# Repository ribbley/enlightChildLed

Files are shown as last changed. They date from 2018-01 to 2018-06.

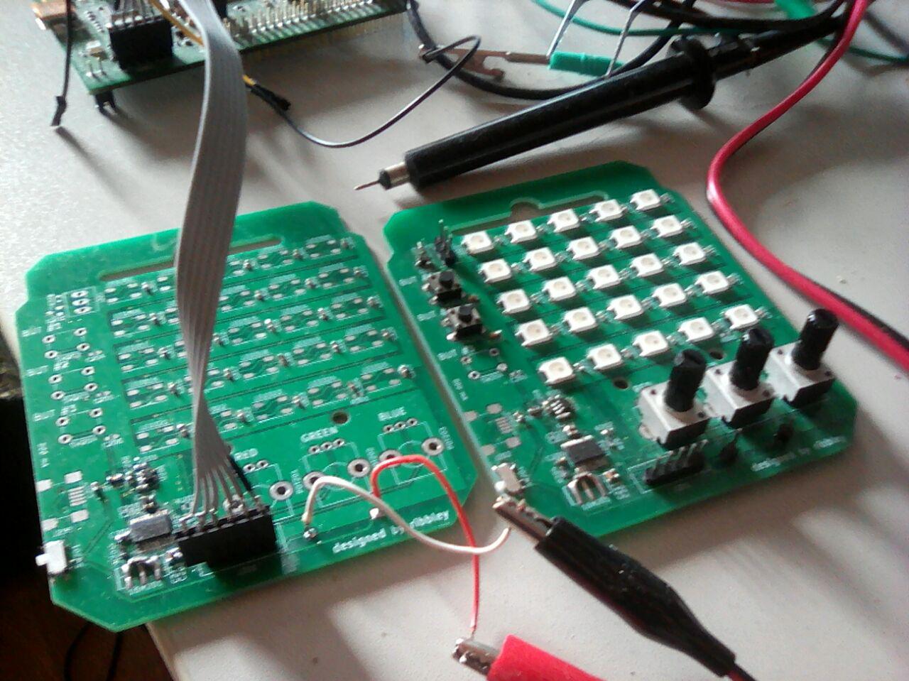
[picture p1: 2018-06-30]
pcb/documentation/enlight_pcbs.jpg

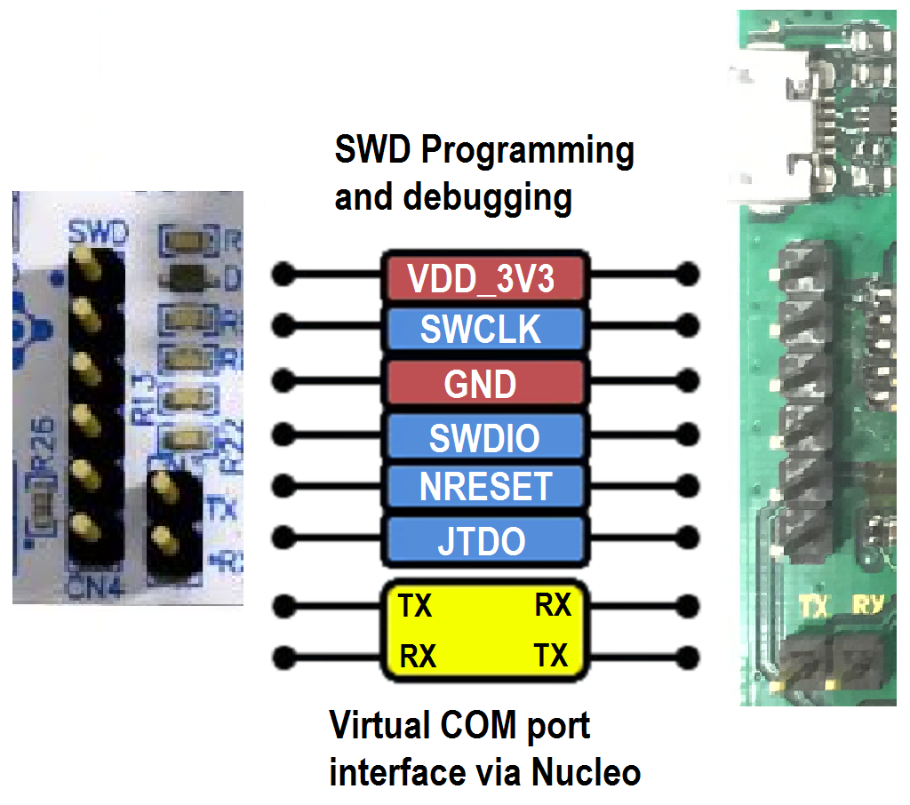
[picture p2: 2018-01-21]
pcb/datasheets/swd_header.png

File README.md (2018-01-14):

# enlightChildLed
Small gadget for kids to play with and learn additive color mixing.

# TODOs:
- add pcb design files (KiCAD)
- document process (design, component search, ordering, assembly, firmware-developing, testing)
- add real photos

# Contact me, if you want to learn more about this project!

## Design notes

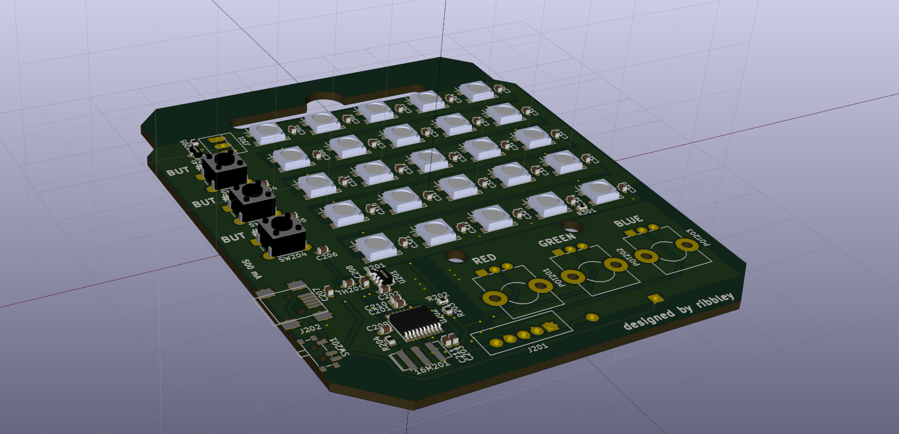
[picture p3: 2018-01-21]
pcb/documentation/enlightChildLed.png

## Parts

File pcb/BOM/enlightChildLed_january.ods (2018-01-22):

Title | Enlight Child LED (worktitle)
Revision | 0.0.1
Date
Generated | Do 21 Dez 2017 11:23:52 CET
Company
Comment 1
Comment 2
Comment 3
Comment 4
Total Parts | 83
Total Unique Parts | 23
Ref | Qty | Value | Footprint | Digikey | Count | Price | Anm.: | Aliexpress | Count | Price | Anm.:
BT201 | 1 | Battery | Battery_Holders:Keystone_2479_3xAAA | BA3AAPC-ND | 10 | 27,42 |  |  | 10 | 8,1 | $ | https://www.aliexpress.com/item/1pcs-Set-18650-Li-ion-Battery-For-Flashlight-For-4-6800mah-18650-Li-ion-Battery-1/32790079648.html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
C202 C209 C201 C325 C324 C323 C322 C321 C320 C319 C318 C317 C316 C315 C314 C313 C312 C311 C310 C309 C308 C307 C306 C305 C304 C303 C302 C301 | 28 | 100n | Capacitors_SMD:C_0603 | 399-1095-2-ND | 4000 | 17,78 |  |  | 500 | 4,99 | $ | https://www.aliexpress.com/item/100pcs-lot-18pF-NPO-Error-5-50V-0603-smd-capacitor/32319259131.html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
C203 | 1 | 1u | Capacitors_SMD:C_0603 | 399-3118-1-ND | 10 | 0,41 |  |  | 200 | 1,3 | $ | https://www.aliexpress.com/item/Free-shipping-0603-SMD-capacitor-1UF-50V-105M-100PCS/32371840299.html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
C210 | 1 | 4.7u | Capacitors_SMD:C_0603 | 1276-6684-1-ND | 10 | 0,88 |  |  | 200 | 2,58 | $ | https://www.aliexpress.com/item/MCIGICM-200pcs-0805-smd-capacitor-ceramic-22pf-100nf-1uf-2-2uf-4-7uf-10uf-47uf-22uf/32842027469.html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
C205 C206 C204 C211 | 4 | 10n | Capacitors_SMD:C_0603 | 732-7933-1-ND | 50 | 1,62 |  |  | 200 | 1,5 | $ | https://www.aliexpress.com/item/MCIGICM-200pcs-0805-smd-capacitor-ceramic-22pf-100nf-1uf-2-2uf-4-7uf-10uf-47uf-22uf/32842027469.html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
C208 C207 | 2 | 10u | Capacitors_SMD:C_0603 | 587-3258-1-ND | 20 | 2,22 |  |  | 200 | 3 | $ | https://www.aliexpress.com/item/MCIGICM-200pcs-0805-smd-capacitor-ceramic-22pf-100nf-1uf-2-2uf-4-7uf-10uf-47uf-22uf/32842027469.html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
J201 | 1 | CONN_01X05 | Connectors:Wafer_Vertical15x5.8x7RM2.5-5 | - |  |  |  | same as I24 |  |  | see below
J202 | 1 | USB_OTG | Connectors:USB_Mini-B | 609-4613-1-ND | 10 | 3,66 |  |  | 10 | 0,87 | $ | https://www.aliexpress.com/item/Free-Shipping-10pcs-Micro-USB-5pin-B-type-Female-Connector-For-Mobile-Phone-Micro-USB/32696736555.html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
J301 | 1 | CONN_01X03_FEMALE | Connectors:PINHEAD1-3 | - |  |  |  |  | 10x40 | 1,07 | $ | https://www.aliexpress.com/item/PinHeader-Male-10lines-40pin-BLACK-2-54mm-Pitch-Straight-PL-11-5-Single-Row/32806123987.html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
LED325 LED324 LED323 LED322 LED321 LED320 LED319 LED318 LED317 LED316 LED315 LED314 LED313 LED312 LED311 LED310 LED309 LED308 LED307 LED306 LED305 LED304 LED303 LED302 LED301 | 25 | WS2812B | LEDs:LED_WS2812B-PLCC4 | NA |  |  |  |  | 200 | 12,15 | 250 needed
16M201 | 1 | Crystal_GND3 | Crystals:Resonator_SMD_muRata_SFSKA-3pin_7.9x3.8mm | 1253-1084-1-ND | 10 | 5,3 |  | not available
POT201 POT202 POT203 | 3 | >500k | Potentiometers:Potentiometer_Bourns_PTV09A-1_Horizontal | PTV09A-4020F-A504-ND | 30 | 16,87 |  | not available
Q201 | 1 | Q_NPN_BCE | TO_SOT_Packages_SMD:SOT-23 | ZXTN07012EFFCT-ND | 10 | 5,12 |  |  | 100 | 1,1 | $ | https://www.aliexpress.com/item/Free-Shipping-100PCS-SMD-S8050-J3Y-NPN-SMD-Transistor-SOT-23/793888983.html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
R204 R201 | 2 | 10k | Resistors_SMD:R_0603 | 311-10KGRCT-ND | 20 | 0,18 |  | set A | 20 | 1,42 | $ | https://www.aliexpress.com/item/Free-shipping-Hot-sale-0603-SMD-Resistor-Kit-Assorted-Kit-1ohm-10M-ohm-1-36valuesX20pcs-720pcs/32359683117.html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
R202 | 1 | 1M | Resistors_SMD:R_0603 | 311-1.0MGRCT-ND | 10 | 0,09 |  | set A | 20
R203 | 1 | 1.5M | Resistors_SMD:R_0603 | 311-1.5MGRCT-ND | 10 | 0,09 |  | set A | 20
R205 | 1 | 5.6k | Resistors_SMD:R_0603 | 541-5.10KHCT-ND | 10 | 0,35 | 5.1k !! | set A | 20
R301 | 1 | 4.7M | Resistors_SMD:R_0603 | 311-5.1MGRCT-ND | 10 | 0,09 |  | set A | 20
SW201 | 1 | SW_DPDT_x2 | Buttons_Switches_SMD:SW_SPDT_PCM12 | ?? |  |  |  | Only 0.3 A | 50 | 5,57 | $ | https://www.aliexpress.com/item/On-Off-2-Position-SPDT-Horizontal-Miniature-SMT-SMD-Slide-Switch/32224673665.html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
SW202 SW203 SW204 | 3 | SW_Push | Buttons_Switches_THT:SW_PUSH_6mm | 450-1650-ND | 30 | 2,2 |  |  | 100 | 1,13 | $ | https://www.aliexpress.com/item/100pcs-6-6-5mm-4pin-Quality-Mini-Micro-Momentary-Tactile-Push-Button-Switch/32753141267.html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
TH201 | 1 | above 500mA | Resistors_SMD:R_0402 | !!! |  |  |  |  | 20 | 1,12 | $ | https://www.aliexpress.com/item/20PCS-0805-500MA-0-5A-SMD-PTC-resettable-fuse/32705112154.html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
U202 | 1 | STM32F031F4Px | Housings_SSOP:TSSOP-20_4.4x6.5mm_Pitch0.65mm | 497-17338-ND | 10 | 12,66 | 16kB vers. | not available
U201 | 1 | AP131-33 | TO_SOT_Packages_SMD:SOT-23-5 | 576-4764-1-ND | 10 | 1 |  | not available
 |  |  |  | total: |  | 97,94 |  | total: |  | 37,638 | Eu
 |  |  |  | Price / Unit : |  | 9,794 |  |  |  | 3,7638
BOM made with KICAD_BOM_WIZARD (https://github.com/HashDefineElectronics/KiCad_BOM_Wizard.git) |  |  |  |  |  |  | Ordered | Type | Count | Price | Anm.: | Link
Generated Do 21 Dez 2017 11:23:52 CET |  |  |  |  |  |  | SMD CAP | 100 nF 0603 | 500 | 4,14 |  | https://www.aliexpress.com/item/100pcs-lot-18pF-NPO-Error-5-50V-0603-smd-capacitor/32319259131.html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
 |  |  |  |  |  |  | SMD CAP | 1 µF 0603 | 200 | 1,08 |  | https://www.aliexpress.com/item/Free-shipping-0603-SMD-capacitor-1UF-50V-105M-100PCS/32371840299.html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
 |  |  |  |  |  |  | BATT HOLDER | 3x AAA | 4 | 2,56 |  | https://www.aliexpress.com/item/1pcs-Set-18650-Li-ion-Battery-For-Flashlight-For-4-6800mah-18650-Li-ion-Battery-1/32790079648.html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
 |  |  |  |  |  |  | SMD CAP KIT | 4.7 µF 0603 | 20 | 2,82 |  | https://www.aliexpress.com/item/0603-SMD-Capacitor-assorted-kit-36values-20pcs-720pcs-1pF-10uF-Samples-Kit-electronic-diy-kit/32817046315.html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
 |  |  |  |  |  |  |  | 10 nF 0603 | 20
 |  |  |  |  |  |  |  | 10 µF 0603 | 20
 |  |  |  |  |  |  | CONN PINS | 5x 40 pin | 200 | 0,69 |  | https://www.aliexpress.com/item/Promotion-5-PCS-Pack-40-Pin-2-54mm-Single-Row-Straight-Male-Female-Pin-Header-Strip/32598438788.html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
 |  |  |  |  |  |  | CONN USB | Micro female | 3 | 2,16 |  | https://www.aliexpress.com/item/Free-Shipping-10pcs-Micro-USB-5pin-B-type-Female-Connector-For-Mobile-Phone-Micro-USB/32696736555.html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
 |  |  |  |  |  |  | NPN TRANS | SOT-23 | 100 | 0,83 |  | https://www.aliexpress.com/item/Free-Shipping-100PCS-SMD-S8050-J3Y-NPN-SMD-Transistor-SOT-23/793888983.html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
 |  |  |  |  |  |  | SMD RES KIT | 10k 0603 | 20 | 1,2 |  | https://www.aliexpress.com/item/Free-shipping-Hot-sale-0603-SMD-Resistor-Kit-Assorted-Kit-1ohm-10M-ohm-1-36valuesX20pcs-720pcs/32359683117.html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
 |  |  |  |  |  |  |  | 1M 0603 | 20
 |  |  |  |  |  |  |  | 1.5M 0603 | 20
 |  |  |  |  |  |  |  | 5.6k 0603 | 20
 |  |  |  |  |  |  |  | 4.7M 0603 | 20
 |  |  |  |  |  |  | SMD PTC | 500 mA 0805 | 20 | 0,93 |  | https://www.aliexpress.com/item/20PCS-0805-500MA-0-5A-SMD-PTC-resettable-fuse/32705112154.html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
 |  |  |  |  |  |  | SMD SWITCH | SPDT slide | 50 | 1,25 |  | https://www.aliexpress.com/item/MINI-micro-Slide-Switch-On-OFF-2-Position-1P2T-SPDT-Miniature-Horizontal-Slide-Switch-SMD-7/32841341185.html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
 |  |  |  |  |  |  | PUSH BUTTON | THT tactile | 100 | 0,94 |  | https://www.aliexpress.com/item/100pcs-6-6-5mm-4pin-Quality-Mini-Micro-Momentary-Tactile-Push-Button-Switch/32753141267.html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
 |  |  |  |  |  |  | SMD MCU | stm32f030f4p6 | 10 | 5,92 |  | https://www.aliexpress.com/item/Free-Shipping-10PCS-STM32F030F4P6-STM32F030/32533209137.html?priceBeautifyAB=1
 |  |  |  |  |  |  | LDO | 3.3V SOT-23-5 | 5 | 0,9 |  | https://www.aliexpress.com/item/Original-XC6228D332VR-G-SOT-23-5-3-3V-Low-Dropout-Linear-Regulator-5pcs-lot/32829424231.html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
 |  |  |  |  |  |  | SMART LED | WS2812B | 100 | 6,92 |  | https://de.aliexpress.com/item/10-1000pcs-WS2812B-4pins-5050-SMD-Black-White-version-WS2812-Individually-Addressable-Digital-RGB-LED-Chip/32453497583.html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
 |  |  |  |  |  |  | POT | 50k RV09 | 10 | 2,34 |  | https://de.aliexpress.com/item/5PCS-LOT-B50K-B503-RV09-Potentiometer-Adjustable-Resistance-12-5mm-Shaft-3-Pins-0932-Vertical-adjustable/32803687010.html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
 |  |  |  |  |  |  | OSC | 8MHz 0805 | 10 | 3,12 |  | https://de.aliexpress.com/store/product/Free-shiiping-10pcs-8MHz-10pF-3Pin-3213-smd-quartz-resonator-Crystal-oscillator/506373_32326095241.html
 |  |  |  |  |  |  |  |  | Sum: | 37,8
 |  |  |  |  |  |  |  |  | Shipping add: | 0,44
 |  |  |  |  |  |  |  |  | TOTAL: | 38,24

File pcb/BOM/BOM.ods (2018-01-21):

 |  | Requirements | URL
Ceramic Crystal Oscillator |  | 16 Mhz | https://de.rs-online.com/web/p/keramik-resonatoren/7027263/
Potentiometer |  | >500kOhm | https://de.rs-online.com/web/p/potenziometer/7377811/
Switch |  | 3 PIN >=500mA | https://www.digikey.de/product-detail/de/e-switch/EG1224/EG2585-ND/502052
Button |  | SMD | https://www.digikey.de/product-detail/de/te-connectivity-alcoswitch-switches/1825910-6/450-1650-ND/1632536
NPN |  | <100ns response | beliebiger SOT-23
Thermistor | PTC | 500 mA Tripping Current | https://www.digikey.de/product-detail/de/bel-fuse-inc/0ZCJ0025AF2E/507-1799-2-ND/4156274
Batteryholder |  |  | http://www.memoryprotectiondevices.com/datasheets/BA3AAPC-datasheet.pdf

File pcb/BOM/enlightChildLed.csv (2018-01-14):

Title | Enlight Child LED (worktitle)
Revision | 0.0.1
Date
Generated | Do 21 Dez 2017 11:23:52 CET
Company
Comment 1
Comment 2
Comment 3
Comment 4
Total Parts | 83
Total Unique Parts | 23
Ref | Qty | Value | Footprint | Digikey | Count | Price | Anm.: | Aliexpress | Count | Price | Anm.:
BT201 | 1 | Battery | Battery_Holders:Keystone_2479_3xAAA | BA3AAPC-ND | 10 | 27.42
C202 C209 C201 C325 C324 C323 C322 C321 C320 C319 C318 C317 C316 C315 C314 C313 C312 C311 C310 C309 C308 C307 C306 C305 C304 C303 C302 C301 | 28 | 100n | Capacitors_SMD:C_0603 | 399-1095-2-ND | 4000 | 17.78
C203 | 1 | 1u | Capacitors_SMD:C_0603 | 399-3118-1-ND | 10 | 0.41
C210 | 1 | 4.7u | Capacitors_SMD:C_0603 | 1276-6684-1-ND | 10 | 0.88
C205 C206 C204 C211 | 4 | 10n | Capacitors_SMD:C_0603 | 732-7933-1-ND | 50 | 1.62
C208 C207 | 2 | 10u | Capacitors_SMD:C_0603 | 587-3258-1-ND | 20 | 2.22
J201 | 1 | CONN_01X05 | Connectors:Wafer_Vertical15x5.8x7RM2.5-5 | -
J202 | 1 | USB_OTG | Connectors:USB_Mini-B | 609-4613-1-ND | 10 | 3.66
J301 | 1 | CONN_01X03_FEMALE | Connectors:PINHEAD1-3 | -
LED325 LED324 LED323 LED322 LED321 LED320 LED319 LED318 LED317 LED316 LED315 LED314 LED313 LED312 LED311 LED310 LED309 LED308 LED307 LED306 LED305 LED304 LED303 LED302 LED301 | 25 | WS2812B | LEDs:LED_WS2812B-PLCC4 | NA |  |  |  |  | 200 | 12.15 | 250 needed
16M201 | 1 | Crystal_GND3 | Crystals:Resonator_SMD_muRata_SFSKA-3pin_7.9x3.8mm | 1253-1084-1-ND | 10 | 5.3
POT201 POT202 POT203 | 3 | >500k | Potentiometers:Potentiometer_Bourns_PTV09A-1_Horizontal | PTV09A-4020F-A504-ND | 30 | 16.87
Q201 | 1 | Q_NPN_BCE | TO_SOT_Packages_SMD:SOT-23 | ZXTN07012EFFCT-ND | 10 | 5.12
R204 R201 | 2 | 10k | Resistors_SMD:R_0603 | 311-10KGRCT-ND | 20 | 0.18
R202 | 1 | 1M | Resistors_SMD:R_0603 | 311-1.0MGRCT-ND | 10 | 0.09
R203 | 1 | 1.5M | Resistors_SMD:R_0603 | 311-1.5MGRCT-ND | 10 | 0.09
R205 | 1 | 5.6k | Resistors_SMD:R_0603 | 541-5.10KHCT-ND | 10 | 0.35 | 5.1k !!
R301 | 1 | 4.7M | Resistors_SMD:R_0603 | 311-5.1MGRCT-ND | 10 | 0.09
SW201 | 1 | SW_DPDT_x2 | Buttons_Switches_SMD:SW_SPDT_PCM12 | ??
SW202 SW203 SW204 | 3 | SW_Push | Buttons_Switches_THT:SW_PUSH_6mm | 450-1650-ND | 30 | 2.2
TH201 | 1 | above 500mA | Resistors_SMD:R_0402 | !!!
U202 | 1 | STM32F031F4Px | Housings_SSOP:TSSOP-20_4.4x6.5mm_Pitch0.65mm | 497-17338-ND | 10 | 12.66 | 16kB vers.
U201 | 1 | AP131-33 | TO_SOT_Packages_SMD:SOT-23-5 | 576-4764-1-ND | 10 | 1
 |  |  |  | total: |  | 97.94 |  | total: |  | 12.15
BOM made with KICAD_BOM_WIZARD (https://github.com/HashDefineElectronics/KiCad_BOM_Wizard.git)
Generated Do 21 Dez 2017 11:23:52 CET

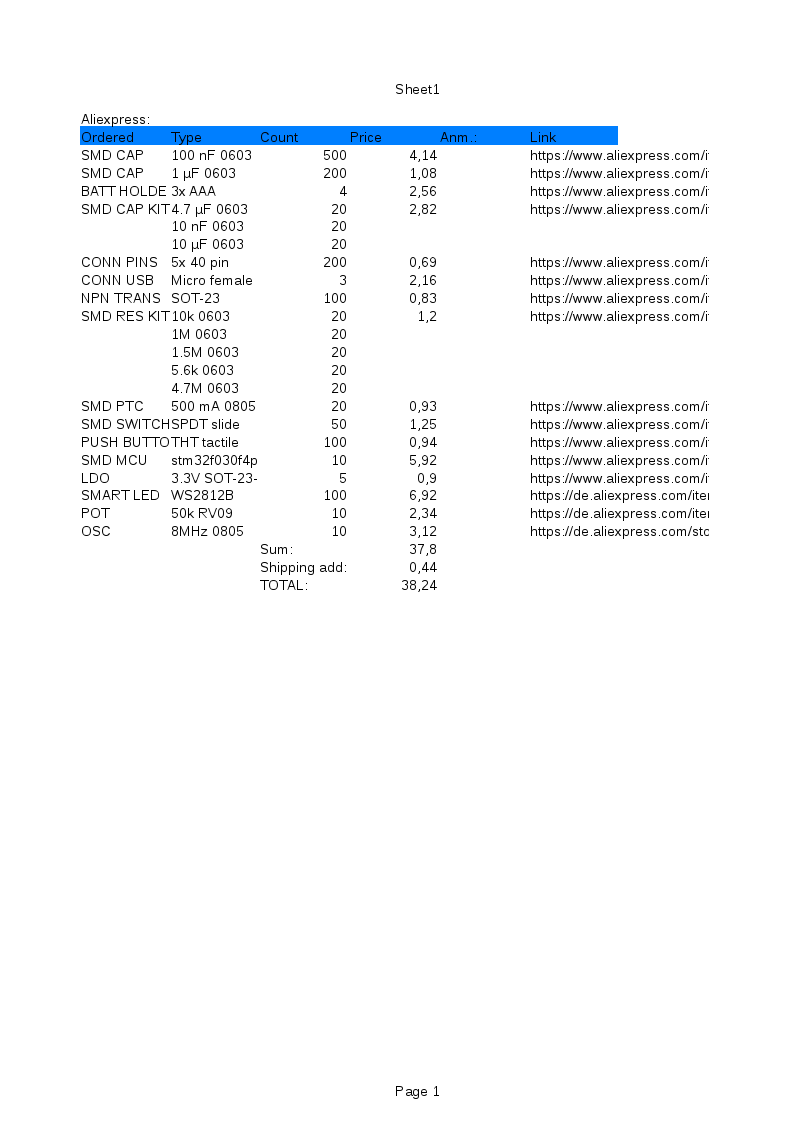
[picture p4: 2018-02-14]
pcb/BOM/order_22_01_2018.png

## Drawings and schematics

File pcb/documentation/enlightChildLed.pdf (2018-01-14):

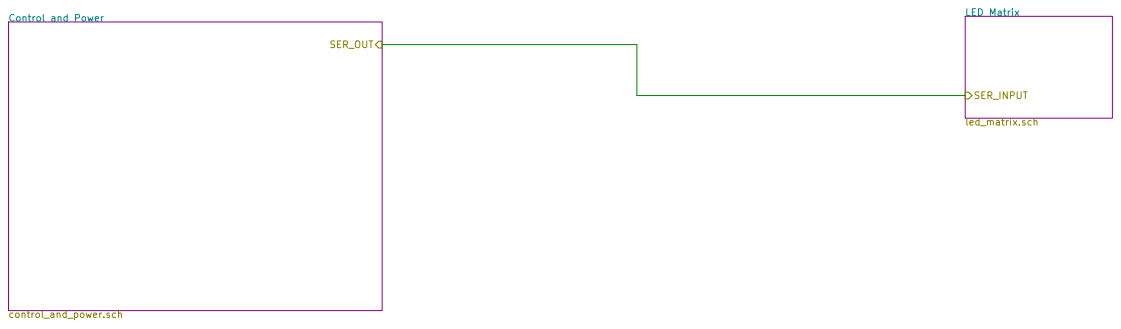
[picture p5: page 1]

File: enlightChildLed.sch Sheet: /
Id: 1/3 Title: Enlight Child LED (worktitle)

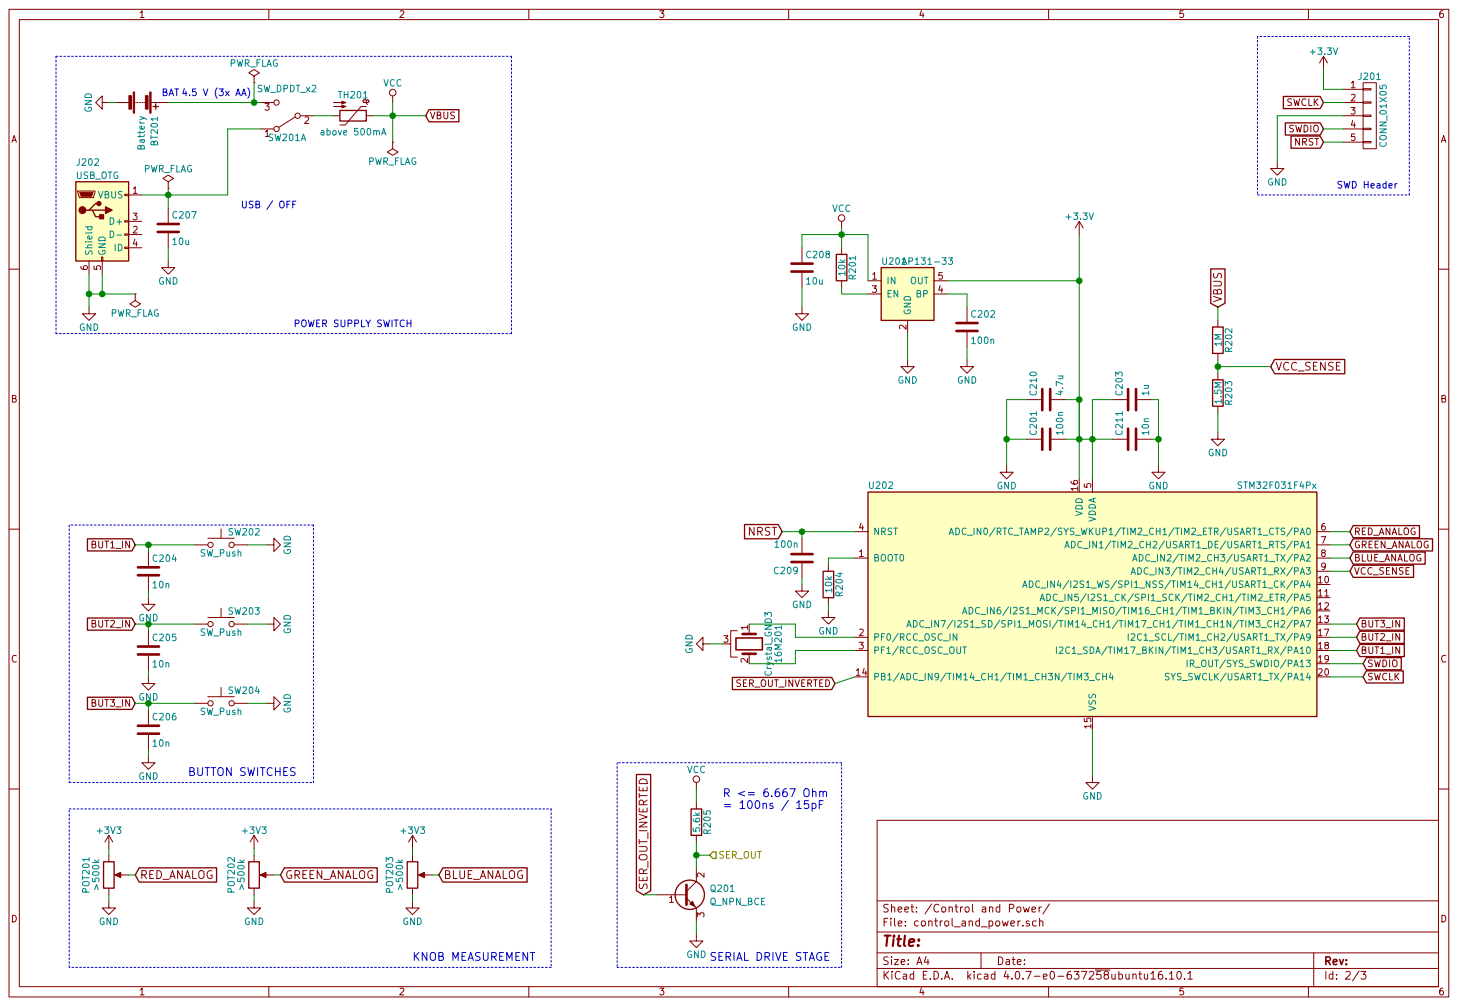
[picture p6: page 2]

2 EN 3 BP 4 OUT 5 U201 AP131-33 GND

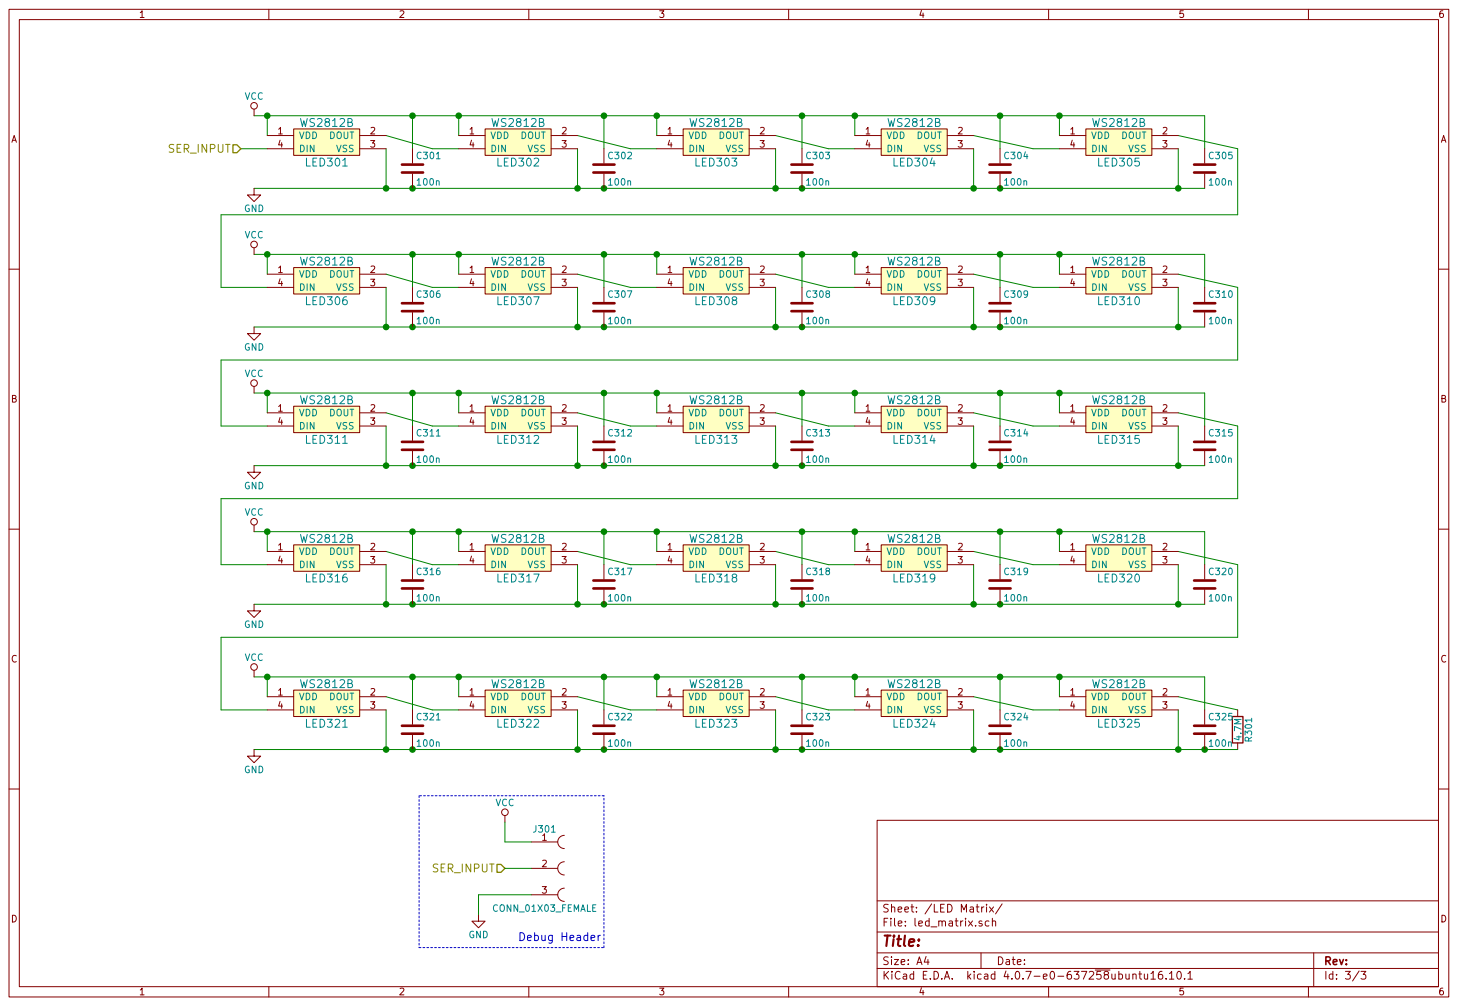
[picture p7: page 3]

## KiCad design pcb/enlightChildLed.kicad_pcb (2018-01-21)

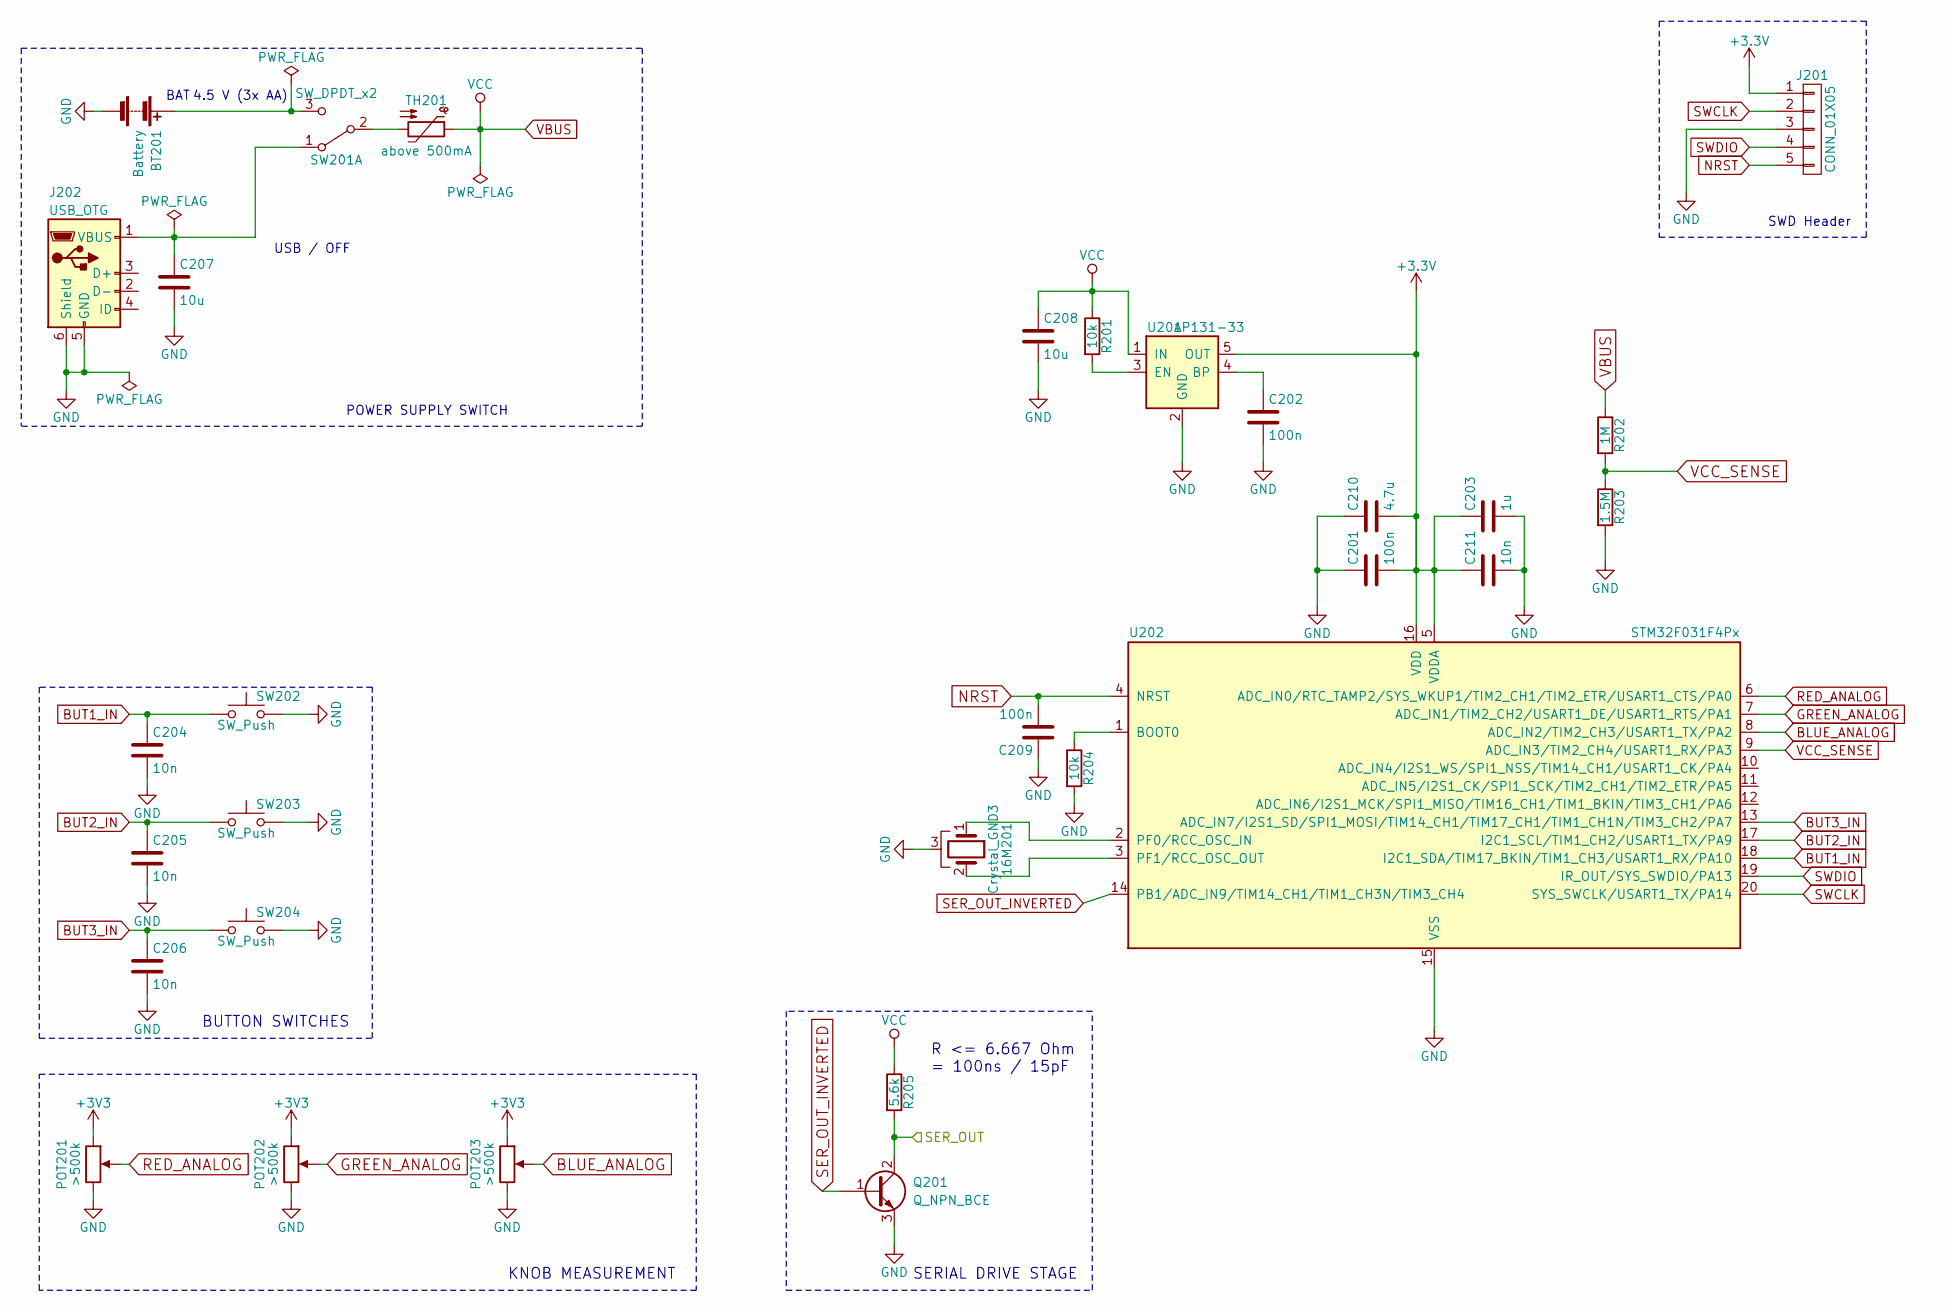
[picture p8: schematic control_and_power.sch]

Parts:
16M201: Crystal_GND3; Resonator_SMD_muRata_SFSKA-3pin_7.9x3.8mm
BT201: Battery; Keystone_2479_3xAAA
C201, C202, C209: 100n; C_0603
C203: 1u; C_0603
C204, C205, C206, C211: 10n; C_0603
C207, C208: 10u; C_0603
C210: 4.7u; C_0603
J201: CONN_01X05; Wafer_Vertical15x5.8x7RM2.5-5
J202: USB_OTG; USB_Mini-B
POT201, POT202, POT203: >500k; Potentiometer_Bourns_PTV09A-1_Horizontal
Q201: Q_NPN_BCE; SOT-23
R201, R204: 10k; R_0603
R202: 1M; R_0603
R203: 1.5M; R_0603
R205: 5.6k; R_0603
SW201: SW_DPDT_x2; SW_SPDT_PCM12
SW202, SW203, SW204: SW_Push; SW_PUSH_6mm
TH201: above 500mA; R_0402
U201: AP131-33; SOT-23-5
U202: STM32F031F4Px; TSSOP-20_4.4x6.5mm_Pitch0.65mm

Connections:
/LED Matrix/SER_INPUT: Q201.2 (C), R205.2; also elsewhere on the board
BLUE_ANALOG: POT203.2, U202.8 (ADC_IN2/TIM2_CH3/USART1_TX/PA2)
BUT1_IN: C204.1, SW202.1, U202.18 (I2C1_SDA/TIM17_BKIN/TIM1_CH3/USART1_RX/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)
BUT2_IN: C205.1, SW203.1, U202.17 (I2C1_SCL/TIM1_CH2/USART1_TX/PA9)
BUT3_IN: C206.1, SW204.1, U202.13 (ADC_IN7/I2S1_SD/SPI1_MOSI/TIM14_CH1/TIM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)
GND: 16M201.3, BT201.2 (-), C201.1, C202.2, C203.2, C204.2, C205.2, C206.2, C207.2, C208.2, C209.1, C210.1, C211.2, J201.3, J202.5 (GND), J202.6 (Shield), POT201.3, POT202.3, POT203.3, Q201.3 (E), R203.2, R204.2, SW202.2, SW203.2, SW204.2, U201.2 (GND), U202.15 (VSS); also elsewhere on the board
GREEN_ANALOG: POT202.2, U202.7 (ADC_IN1/TIM2_CH2/USART1_DE/USART1_RTS/P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)
NRST: C209.2, J201.5, U202.4 (NRST)
unnamed: 16M201.1, U202.2 (PF0/RCC_OSC_IN)
unnamed: 16M201.2, U202.3 (PF1/RCC_OSC_OUT)
unnamed: BT201.1 (+), SW201.3 (C)
unnamed: C202.1, U201.4 (BP)
unnamed: C207.1, J202.1 (VBUS), SW201.1 (A)
unnamed: R201.2, U201.3 (EN)
unnamed: R204.1, U202.1 (BOOT0)
unnamed: SW201.2 (B), TH201.2
RED_ANALOG: POT201.2, U202.6 (ADC_IN0/RTC_TAMP2/SYS_WKUP1/TIM2_CH1/TI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)
SER_OUT_INVERTED: Q201.1 (B), U202.14 (PB1/ADC_IN9/TIM14_CH1/TIM1_CH3N/TIM3_CH4)
SWCLK: J201.2, U202.20 (SYS_SWCLK/USART1_TX/PA14)
SWDIO: J201.4, U202.19 (IR_OUT/SYS_SWDIO/PA13)
VBUS: C208.1, R201.1, R202.1, R205.1, TH201.1, U201.1 (IN); also elsewhere on the board
VCC_SENSE: R202.2, R203.1, U202.9 (ADC_IN3/TIM2_CH4/USART1_RX/PA3)

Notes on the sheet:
SWD Header
USB / OFF
BAT
POWER SUPPLY SWITCH
4.5 V (3x AA)
KNOB MEASUREMENT
R <= 6.667 Ohm = 100ns / 15pF
SERIAL DRIVE STAGE
BUTTON SWITCHES

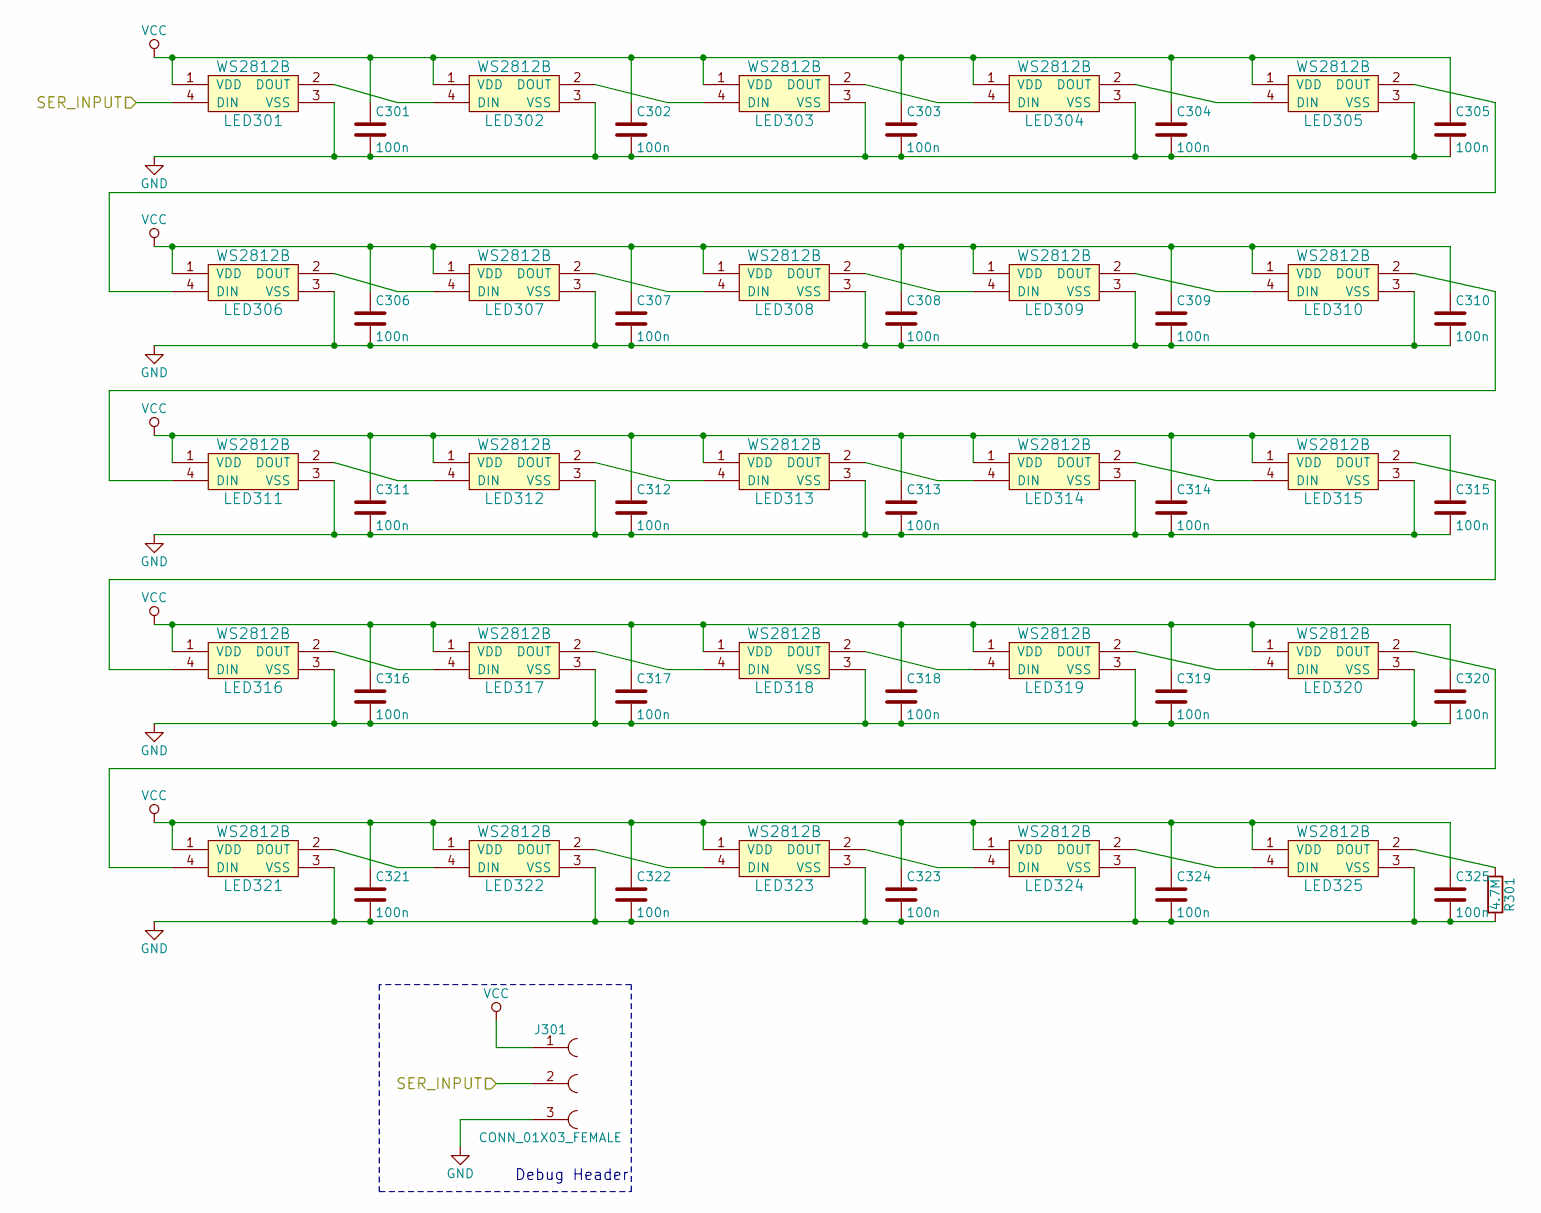
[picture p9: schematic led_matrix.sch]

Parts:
C301, C302, C303, C304, C305, C306, C307, C308, C309, C310, C311, C312, C313, C314, C315, C316, C317, C318, C319, C320, C321, C322, C323, C324, C325: 100n; C_0603
J301: CONN_01X03_FEMALE; PINHEAD1-3
LED301, LED302, LED303, LED304, LED305, LED306, LED307, LED308, LED309, LED310, LED311, LED312, LED313, LED314, LED315, LED316, LED317, LED318, LED319, LED320, LED321, LED322, LED323, LED324, LED325: WS2812B; LED_WS2812B-PLCC4
R301: 4.7M; R_0603

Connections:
/LED Matrix/SER_INPUT: J301.2, LED301.4 (DIN); also elsewhere on the board
GND: C301.2, C302.2, C303.2, C304.2, C305.2, C306.2, C307.2, C308.2, C309.2, C310.2, C311.2, C312.2, C313.2, C314.2, C315.2, C316.2, C317.2, C318.2, C319.2, C320.2, C321.2, C322.2, C323.2, C324.2, C325.2, J301.3, LED301.3 (VSS), LED302.3 (VSS), LED303.3 (VSS), LED304.3 (VSS), LED305.3 (VSS), LED306.3 (VSS), LED307.3 (VSS), LED308.3 (VSS), LED309.3 (VSS), LED310.3 (VSS), LED311.3 (VSS), LED312.3 (VSS), LED313.3 (VSS), LED314.3 (VSS), LED315.3 (VSS), LED316.3 (VSS), LED317.3 (VSS), LED318.3 (VSS), LED319.3 (VSS), LED320.3 (VSS), LED321.3 (VSS), LED322.3 (VSS), LED323.3 (VSS), LED324.3 (VSS), LED325.3 (VSS), R301.2; also elsewhere on the board
unnamed: LED301.2 (DOUT), LED302.4 (DIN)
unnamed: LED302.2 (DOUT), LED303.4 (DIN)
unnamed: LED303.2 (DOUT), LED304.4 (DIN)
unnamed: LED304.2 (DOUT), LED305.4 (DIN)
unnamed: LED305.2 (DOUT), LED306.4 (DIN)
unnamed: LED306.2 (DOUT), LED307.4 (DIN)
unnamed: LED307.2 (DOUT), LED308.4 (DIN)
unnamed: LED308.2 (DOUT), LED309.4 (DIN)
unnamed: LED309.2 (DOUT), LED310.4 (DIN)
unnamed: LED310.2 (DOUT), LED311.4 (DIN)
unnamed: LED311.2 (DOUT), LED312.4 (DIN)
unnamed: LED312.2 (DOUT), LED313.4 (DIN)
unnamed: LED313.2 (DOUT), LED314.4 (DIN)
unnamed: LED314.2 (DOUT), LED315.4 (DIN)
unnamed: LED315.2 (DOUT), LED316.4 (DIN)
unnamed: LED316.2 (DOUT), LED317.4 (DIN)
unnamed: LED317.2 (DOUT), LED318.4 (DIN)
unnamed: LED318.2 (DOUT), LED319.4 (DIN)
unnamed: LED319.2 (DOUT), LED320.4 (DIN)
unnamed: LED320.2 (DOUT), LED321.4 (DIN)
unnamed: LED321.2 (DOUT), LED322.4 (DIN)
unnamed: LED322.2 (DOUT), LED323.4 (DIN)
unnamed: LED323.2 (DOUT), LED324.4 (DIN)
unnamed: LED324.2 (DOUT), LED325.4 (DIN)
unnamed: LED325.2 (DOUT), R301.1
VBUS: C301.1, C302.1, C303.1, C304.1, C305.1, C306.1, C307.1, C308.1, C309.1, C310.1, C311.1, C312.1, C313.1, C314.1, C315.1, C316.1, C317.1, C318.1, C319.1, C320.1, C321.1, C322.1, C323.1, C324.1, C325.1, J301.1, LED301.1 (VDD), LED302.1 (VDD), LED303.1 (VDD), LED304.1 (VDD), LED305.1 (VDD), LED306.1 (VDD), LED307.1 (VDD), LED308.1 (VDD), LED309.1 (VDD), LED310.1 (VDD), LED311.1 (VDD), LED312.1 (VDD), LED313.1 (VDD), LED314.1 (VDD), LED315.1 (VDD), LED316.1 (VDD), LED317.1 (VDD), LED318.1 (VDD), LED319.1 (VDD), LED320.1 (VDD), LED321.1 (VDD), LED322.1 (VDD), LED323.1 (VDD), LED324.1 (VDD), LED325.1 (VDD); also elsewhere on the board

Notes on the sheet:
Debug Header

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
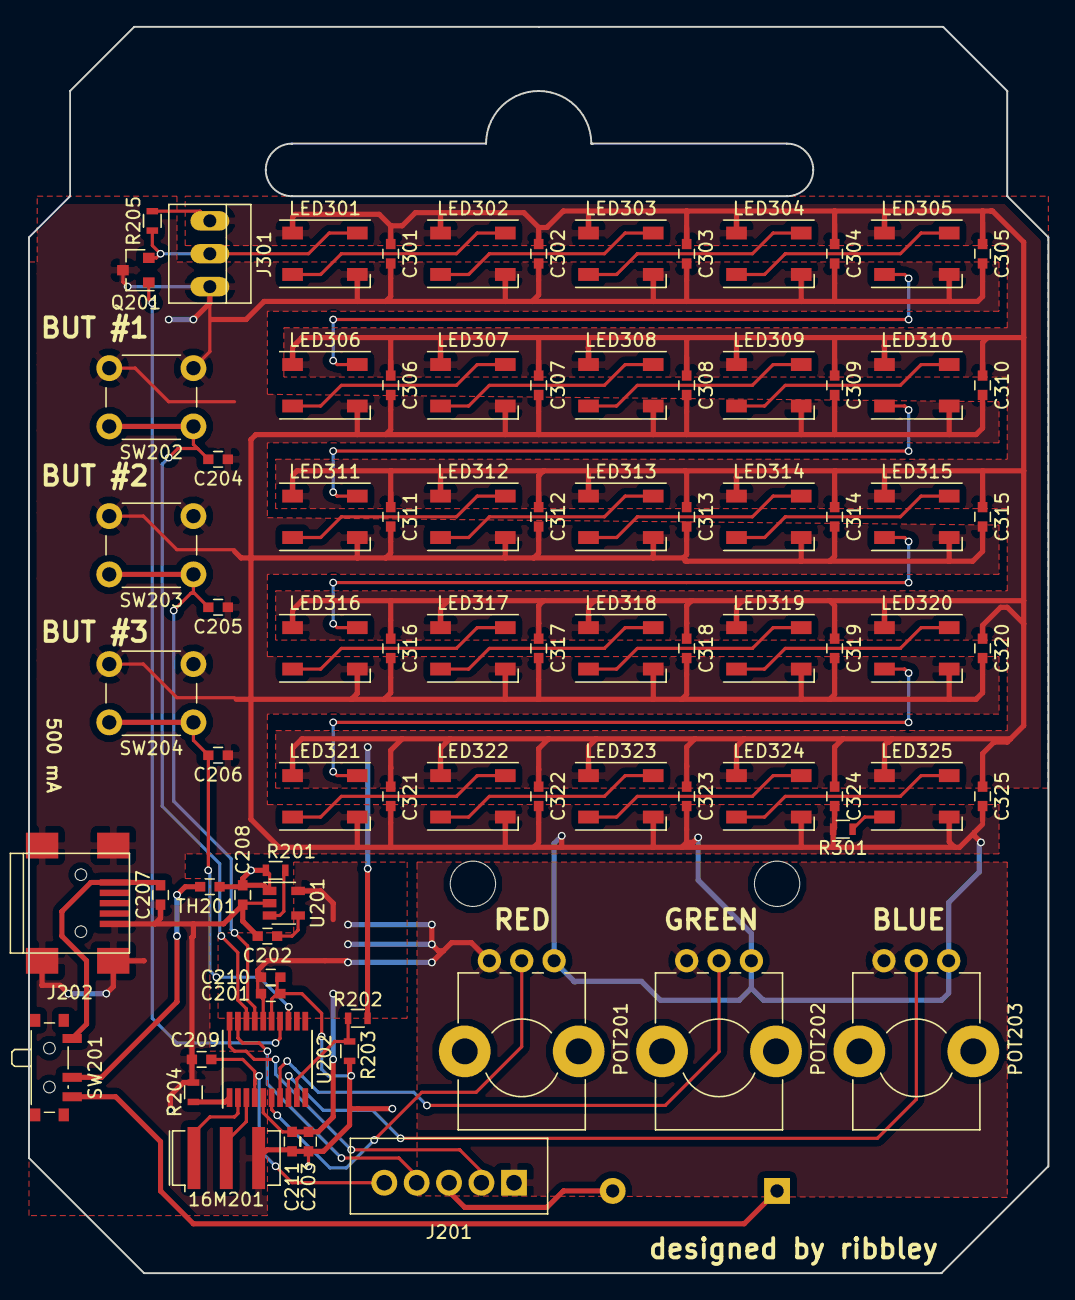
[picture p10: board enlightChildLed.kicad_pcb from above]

Board: 2 copper layers, 78.7 x 96.3 mm, 83 parts (1 on the bottom side), 48 nets.

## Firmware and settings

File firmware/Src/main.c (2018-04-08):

/**
  ******************************************************************************
  * File Name          : main.c
  * Description        : Main program body
  ******************************************************************************
  ** This notice applies to any and all portions of this file
  * that are not between comment pairs USER CODE BEGIN and
  * USER CODE END. Other portions of this file, whether
  * inserted by the user or by software development tools
  * are owned by their respective copyright owners.
  *
  * COPYRIGHT(c) 2018 STMicroelectronics
  *
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
  ******************************************************************************
  */

/* Includes ------------------------------------------------------------------*/
#include "main.h"
#include "stm32f0xx_hal.h"

/* USER CODE BEGIN Includes */
#include <string.h>

/* USER CODE END Includes */

ADC_HandleTypeDef hadc;
DMA_HandleTypeDef hdma_adc;

/* USER CODE BEGIN PV */
uint8_t grb_array_size = 1;
uint8_t max_power = 0x08;

struct PIXEL {
  uint8_t green;
  uint8_t red;
  uint8_t blue;
};

struct PIXEL grb_array[25];

/* USER CODE END PV */

void SystemClock_Config(void);
static void MX_GPIO_Init(void);
static void MX_DMA_Init(void);
static void MX_ADC_Init(void);

/* USER CODE BEGIN PFP */
extern void wait_0h();
extern void wait_0l();
extern void wait_1h();
extern void wait_1l();
extern void wait_reset();

void checkButtons();
void updateColors();
void setPixel(uint8_t x, uint8_t y, uint8_t green, uint8_t red, uint8_t blue);
void setColumn(uint8_t column, uint8_t green, uint8_t red, uint8_t blue);
void setRow(uint8_t row, uint8_t green, uint8_t red, uint8_t blue);
void setAll(uint8_t green, uint8_t red, uint8_t blue);

void transmit_zero();
void transmit_one();
void transmit_reset();

/* USER CODE END PFP */

int main(void)
{

  /* MCU Configuration----------------------------------------------------------*/

  /* Reset of all peripherals, Initializes the Flash interface and the Systick. */
  HAL_Init();

  /* Configure the system clock */
  SystemClock_Config();

  /* Initialize all configured peripherals */
  MX_GPIO_Init();
  MX_DMA_Init();
  MX_ADC_Init();

  /* Infinite loop */
  /* USER CODE BEGIN WHILE */
  uint32_t times = 0;
  memset(&grb_array, 0, sizeof(struct PIXEL) * 25);

  //setRow(2, 0, 0, max_power);

  while (1)
  {
    transmit_zero();
    transmit_zero();

  /* USER CODE END WHILE */

  /* USER CODE BEGIN 3 */

  }
  /* USER CODE END 3 */

}

/** System Clock Configuration
*/
void SystemClock_Config(void)
{

  RCC_OscInitTypeDef RCC_OscInitStruct;
  RCC_ClkInitTypeDef RCC_ClkInitStruct;

    /**Initializes the CPU, AHB and APB busses clocks
    */
  RCC_OscInitStruct.OscillatorType = RCC_OSCILLATORTYPE_HSI;
  RCC_OscInitStruct.HSIState = RCC_HSI_ON;
  RCC_OscInitStruct.HSICalibrationValue = 16;
  RCC_OscInitStruct.PLL.PLLState = RCC_PLL_ON;
  RCC_OscInitStruct.PLL.PLLSource = RCC_PLLSOURCE_HSI;
  RCC_OscInitStruct.PLL.PLLMUL = RCC_PLL_MUL12;
  RCC_OscInitStruct.PLL.PREDIV = RCC_PREDIV_DIV1;
  if (HAL_RCC_OscConfig(&RCC_OscInitStruct) != HAL_OK)
  {
    _Error_Handler(__FILE__, __LINE__);
  }

    /**Initializes the CPU, AHB and APB busses clocks
    */
  RCC_ClkInitStruct.ClockType = RCC_CLOCKTYPE_HCLK|RCC_CLOCKTYPE_SYSCLK
                              |RCC_CLOCKTYPE_PCLK1;
  RCC_ClkInitStruct.SYSCLKSource = RCC_SYSCLKSOURCE_PLLCLK;
  RCC_ClkInitStruct.AHBCLKDivider = RCC_SYSCLK_DIV1;
  RCC_ClkInitStruct.APB1CLKDivider = RCC_HCLK_DIV1;

  if (HAL_RCC_ClockConfig(&RCC_ClkInitStruct, FLASH_LATENCY_1) != HAL_OK)
  {
    _Error_Handler(__FILE__, __LINE__);
  }

    /**Configure the Systick interrupt time
    */
  HAL_SYSTICK_Config(HAL_RCC_GetHCLKFreq()/1000);

    /**Configure the Systick
    */
  HAL_SYSTICK_CLKSourceConfig(SYSTICK_CLKSOURCE_HCLK);

  /* SysTick_IRQn interrupt configuration */
  HAL_NVIC_SetPriority(SysTick_IRQn, 0, 0);
}

/* ADC init function */
static void MX_ADC_Init(void)
{

  ADC_ChannelConfTypeDef sConfig;

    /**Configure the global features of the ADC (Clock, Resolution, Data Alignment and number of conversion)
    */
  hadc.Instance = ADC1;
  hadc.Init.ClockPrescaler = ADC_CLOCK_SYNC_PCLK_DIV4;
  hadc.Init.Resolution = ADC_RESOLUTION_12B;
  hadc.Init.DataAlign = ADC_DATAALIGN_RIGHT;
  hadc.Init.ScanConvMode = ADC_SCAN_DIRECTION_FORWARD;
  hadc.Init.EOCSelection = ADC_EOC_SINGLE_CONV;
  hadc.Init.LowPowerAutoWait = DISABLE;
  hadc.Init.LowPowerAutoPowerOff = DISABLE;
  hadc.Init.ContinuousConvMode = ENABLE;
  hadc.Init.DiscontinuousConvMode = DISABLE;
  hadc.Init.ExternalTrigConv = ADC_SOFTWARE_START;
  hadc.Init.ExternalTrigConvEdge = ADC_EXTERNALTRIGCONVEDGE_NONE;
  hadc.Init.DMAContinuousRequests = ENABLE;
  hadc.Init.Overrun = ADC_OVR_DATA_PRESERVED;
  if (HAL_ADC_Init(&hadc) != HAL_OK)
  {
    _Error_Handler(__FILE__, __LINE__);
  }

    /**Configure for the selected ADC regular channel to be converted.
    */
  sConfig.Channel = ADC_CHANNEL_0;
  sConfig.Rank = ADC_RANK_CHANNEL_NUMBER;
  sConfig.SamplingTime = ADC_SAMPLETIME_239CYCLES_5;
  if (HAL_ADC_ConfigChannel(&hadc, &sConfig) != HAL_OK)
  {
    _Error_Handler(__FILE__, __LINE__);
  }

    /**Configure for the selected ADC regular channel to be converted.
    */
  sConfig.Channel = ADC_CHANNEL_1;
  if (HAL_ADC_ConfigChannel(&hadc, &sConfig) != HAL_OK)
  {
    _Error_Handler(__FILE__, __LINE__);
  }

    /**Configure for the selected ADC regular channel to be converted.
    */
  sConfig.Channel = ADC_CHANNEL_2;
  if (HAL_ADC_ConfigChannel(&hadc, &sConfig) != HAL_OK)
  {
    _Error_Handler(__FILE__, __LINE__);
  }

    /**Configure for the selected ADC regular channel to be converted.
    */
  sConfig.Channel = ADC_CHANNEL_3;
  if (HAL_ADC_ConfigChannel(&hadc, &sConfig) != HAL_OK)
  {
    _Error_Handler(__FILE__, __LINE__);
  }

}

/**
  * Enable DMA controller clock
  */
static void MX_DMA_Init(void)
{
  /* DMA controller clock enable */
  __HAL_RCC_DMA1_CLK_ENABLE();

  /* DMA interrupt init */
  /* DMA1_Channel1_IRQn interrupt configuration */
  HAL_NVIC_SetPriority(DMA1_Channel1_IRQn, 0, 0);
  HAL_NVIC_EnableIRQ(DMA1_Channel1_IRQn);

}

/** Configure pins as
        * Analog
        * Input
        * Output
        * EVENT_OUT
        * EXTI
*/
static void MX_GPIO_Init(void)
{

  GPIO_InitTypeDef GPIO_InitStruct;

  /* GPIO Ports Clock Enable */
  __HAL_RCC_GPIOF_CLK_ENABLE();
  __HAL_RCC_GPIOA_CLK_ENABLE();
  __HAL_RCC_GPIOB_CLK_ENABLE();

  /*Configure GPIO pin Output Level */
  HAL_GPIO_WritePin(SER_OUT_INVERTED_GPIO_Port, SER_OUT_INVERTED_Pin, GPIO_PIN_RESET);

  /*Configure GPIO pins : BUT3_IN_Pin BUT2_IN_Pin BUT1_IN_Pin */
  GPIO_InitStruct.Pin = BUT3_IN_Pin|BUT2_IN_Pin|BUT1_IN_Pin;
  GPIO_InitStruct.Mode = GPIO_MODE_INPUT;
  GPIO_InitStruct.Pull = GPIO_PULLUP;
  HAL_GPIO_Init(GPIOA, &GPIO_InitStruct);

  /*Configure GPIO pin : SER_OUT_INVERTED_Pin */
  GPIO_InitStruct.Pin = SER_OUT_INVERTED_Pin;
  GPIO_InitStruct.Mode = GPIO_MODE_OUTPUT_PP;
  GPIO_InitStruct.Pull = GPIO_PULLUP;
  GPIO_InitStruct.Speed = GPIO_SPEED_FREQ_HIGH;
  HAL_GPIO_Init(SER_OUT_INVERTED_GPIO_Port, &GPIO_InitStruct);

}

/* USER CODE BEGIN 4 */

void setPixel(uint8_t x, uint8_t y, uint8_t green, uint8_t red, uint8_t blue){
  grb_array[x + (5 * y)].green = green;
  grb_array[x + (5 * y)].red = red;
  grb_array[x + (5 * y)].blue = blue;
}

void setColumn(uint8_t column, uint8_t green, uint8_t red, uint8_t blue){
  setPixel(column, 0, green, red, blue);
  setPixel(column, 1, green, red, blue);
  setPixel(column, 2, green, red, blue);
  setPixel(column, 3, green, red, blue);
  setPixel(column, 4, green, red, blue);
}

void setRow(uint8_t row, uint8_t green, uint8_t red, uint8_t blue){
  setPixel(0, row, green, red, blue);
  setPixel(1, row, green, red, blue);
  setPixel(2, row, green, red, blue);
  setPixel(3, row, green, red, blue);
  setPixel(4, row, green, red, blue);
}

void setAll(uint8_t green, uint8_t red, uint8_t blue){
  setRow(0, green, red, blue);
  setRow(1, green, red, blue);
  setRow(2, green, red, blue);
  setRow(3, green, red, blue);
  setRow(4, green, red, blue);
}

void updateColors(){
  transmit_reset();

  for (uint8_t j = 0; j < grb_array_size; j++){
    for (uint8_t i  = 24; i > 0 ; i--){
      uint32_t tmp = (grb_array[j].green << 16) | (grb_array[j].red << 8) | grb_array[j].blue;
      (tmp & (1 << (i-1)))?transmit_one():transmit_zero();
    }
  }
  transmit_reset();
  HAL_Delay(1);
}

/*
 * SER_OUT_INVERTED_GPIO_Port->BSRR = (uint32_t)SER_OUT_INVERTED_Pin;
 * SER_OUT_INVERTED_GPIO_Port->BRR = (uint32_t)SER_OUT_INVERTED_Pin;
 */

#define __SER_OUT_SET SER_OUT_INVERTED_GPIO_Port->BSRR = (uint32_t)SER_OUT_INVERTED_Pin
#define __SER_OUT_RESET SER_OUT_INVERTED_GPIO_Port->BRR = (uint32_t)SER_OUT_INVERTED_Pin

void transmit_zero(){
  __SER_OUT_RESET;
  wait_0h();
  __SER_OUT_SET;
  wait_0l();
}

void transmit_one(){
  __SER_OUT_RESET;
  wait_1h();
  __SER_OUT_SET;
  wait_1l();
}
void transmit_reset(){
  __SER_OUT_SET;
  wait_reset();
  __SER_OUT_RESET;
}

void checkButtons(){
	uint8_t buttons = 0;
	if (HAL_GPIO_ReadPin(BUT1_IN_GPIO_Port, BUT1_IN_Pin == GPIO_PIN_RESET)){
		buttons |= 0x01;
	}
	if (HAL_GPIO_ReadPin(BUT2_IN_GPIO_Port, BUT2_IN_Pin) == GPIO_PIN_RESET){
		buttons |= 0x02;
	}
	if (HAL_GPIO_ReadPin(BUT3_IN_GPIO_Port, BUT3_IN_Pin) == GPIO_PIN_RESET){
		buttons |= 0x04;
	}
}

/* USER CODE END 4 */
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


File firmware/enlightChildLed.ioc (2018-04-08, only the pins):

Mcu.UserName=STM32F030F4Px
PA0.GPIO_Label=RED_ANALOG
PA0.Signal=ADC_IN0
PA1.GPIO_Label=GREEN_ANALOG
PA1.Signal=ADC_IN1
PA10.GPIO_Label=BUT1_IN
PA10.Signal=GPIO_Input
PA13.Signal=SYS_SWDIO
PA14.Signal=SYS_SWCLK
PA2.GPIO_Label=BLUE_ANALOG
PA2.Signal=ADC_IN2
PA3.GPIO_Label=VCC_SENSE
PA3.Signal=ADC_IN3
PA7.GPIO_Label=BUT3_IN
PA7.Signal=GPIO_Input
PA9.GPIO_Label=BUT2_IN
PA9.Signal=GPIO_Input
PB1.GPIO_Label=SER_OUT_INVERTED
PB1.Signal=GPIO_Output
PF0-OSC_IN.Signal=RCC_OSC_IN
PF1-OSC_OUT.Signal=RCC_OSC_OUT

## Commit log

2018-01-14 first commit, pcb design pending
    [enlightChildLed.csv, enlightChildLed.ods]
2018-01-21 added pcb files from main pc
    [BOM.ods, control_and_power.sch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]
2018-01-22 first component order executed
    [enlightChildLed_january.ods, order_22_01_2018.ods]
2018-02-21 switched to stm32f030f4p6
2018-02-24 cleaning repo
    [stlinkv2-1_clone.cfg, stlinkv2_clone.cfg, stm32f0-openocd.cfg]
2018-03-20 some led controlling functions
2018-04-08 some testing with assembler gpio banging
2018-06-30 added real pcb photos

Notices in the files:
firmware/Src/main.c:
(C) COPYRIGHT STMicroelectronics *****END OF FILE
